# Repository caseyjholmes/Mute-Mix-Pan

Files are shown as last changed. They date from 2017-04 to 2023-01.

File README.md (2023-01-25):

# Mute-Mix-Pan

NOTE:
this is an outdated version of my mixer. use the new MMPV3 repository files

5 Channel Mono Mutable Mixer with Pan output for Eurorack

A simple knob controlled 5 channel mono eurorack mixer with mute switches, master volume and panning balance outputs. 
Component values are printed on the board. Minimum component size is 0805.

Install switches first, then front panel. The switches are "tall". Solder in jacks to the right height after the switches are in place. Finally, you can solder in the potentiometers. 

Panel has been added now.

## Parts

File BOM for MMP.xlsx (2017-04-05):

VR1-5 | Vertical B1M Linear 9mm rotary potentiometer | Thonk https://www.thonk.co.uk/shop/alpha-9mm-pots/
VR6, VR7 | Vertical B10K Linear 9mm rotary potentiometer | Thonk https://www.thonk.co.uk/shop/alpha-9mm-pots/
R1-R5,R17-R21, R25, R26 | 1K 0805 SMD resistor 603-RC0805FR-071K5L | Mouser
R6-R16, R22, R23, R24 | 100K 0805 SMD resistor 603-RC0805FR-07100KL | Mouser
C1-5 | 10uf 35v Aluminum Electrolytic Cap 667-EEE-FK1V100UR | Mouser
C6,C7 | 47uf 35v Aluminum Electrolytic Cap 667-EEE-FK1V470P | Mouser
C8-C11 | 100n 25v 0805 SMD Cap 81-GRM40X104K25L | Mouser
D1,D2 | 1N5817 Through Hole diodes 621-1N5817 | Mouser
LED1-5 | 3mm Through Hold Light Emitting Diodes 604-WP710A10GT | Mouser
LED6 | 5mm Through Hole Light Emitting Diode 604-WP1503GD | Mouser
IC1,IC2 | TL074 Quad Op Amp SMD SOIC14 package 595-TL074CDR | Mouser
POWER (header) | 2 row 5 pin .1" spacing Power Header 649-67996-410HLF | Mouser
J1-9 | Thonkicon 3.5mm Jack PJ301M-12 | Thonk, Modular Addict
SW1-5 | On/On SPDT Miniture (not micro) Toggle Switches | Thonk https://www.thonk.co.uk/shop/turing-mk-ii-write-switch/
knobs | 7 knobs to fit potentiometers | Ebay, AliExpress, Mouser, Modular Addict, Thonk

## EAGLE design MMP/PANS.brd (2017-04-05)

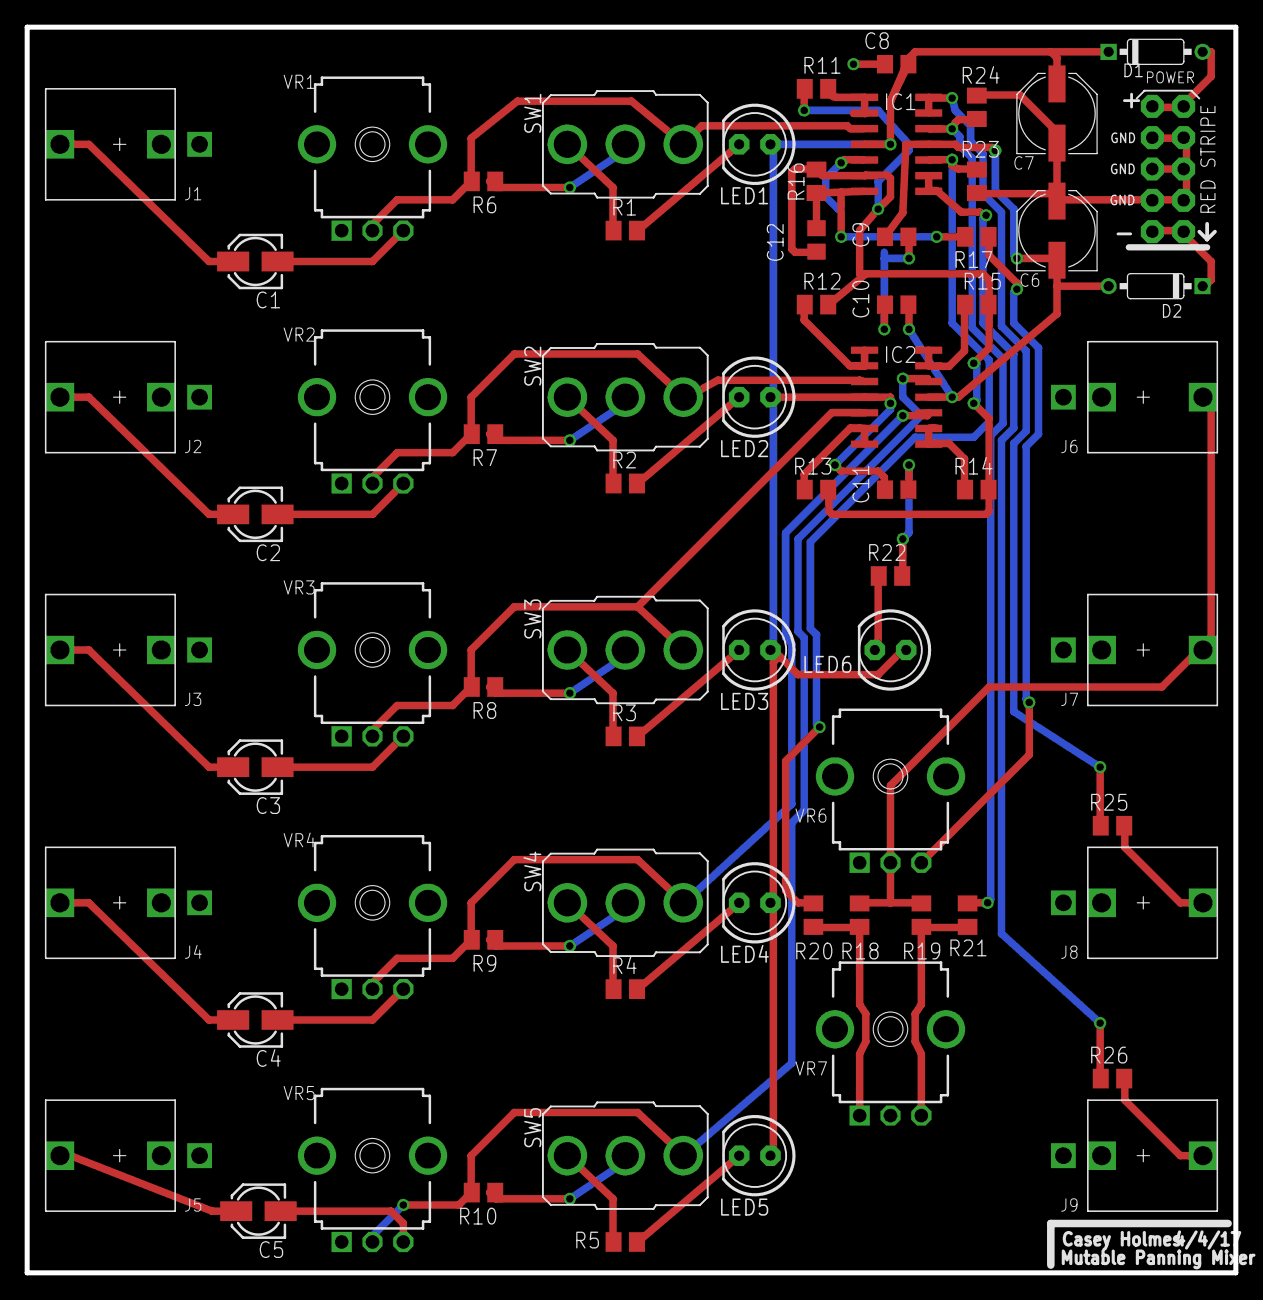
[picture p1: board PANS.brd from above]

Board: 2 copper layers, 98.0 x 101.0 mm, 70 parts (0 on the bottom side), 48 nets.

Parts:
C1, C2, C3, C4, C5: 10uf; 153CLV-0405
C6, C7: 47uf; PANASONIC_D
C8, C9, C10, C11: 100n; C0805
C12: XXX; C0805
D1, D2: 1N5817; DO35-7
IC1, IC2: TL074; SO14
J1, J2, J3, J4, J5, J6, J7, J8, J9: THONKICONNOLD; THONKICONN
LED1, LED2, LED3, LED4, LED5, LED6: green; LED5MM
R1, R2, R3, R4, R5, R17, R18, R19, R20, R21, R25, R26: 1K; M0805
R6, R7, R8, R9, R10, R11, R12, R13, R14, R15, R16, R22, R23, R24: 100K; M0805
SV1: SV1; EURO_PWR_HEADER_FAT
SW1, SW2, SW3, SW4, SW5: on/on; M9040P
VR1, VR2, VR3, VR4, VR5: 1M; 9MM_SNAP-IN_POT
VR6, VR7: 10K; 9MM_SNAP-IN_POT

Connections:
GND: C6.+, C7.-, C8.1, C9.1, C10.1, C11.2, IC1.5, J1.P$1_SLEEVE, J2.P$1_SLEEVE, J3.P$1_SLEEVE, J4.P$1_SLEEVE, J5.P$1_SLEEVE, J6.P$1_SLEEVE, J7.P$1_SLEEVE, J8.P$1_SLEEVE, J9.P$1_SLEEVE, R6.1, R7.1, R8.1, R9.1, R10.1, R22.2, R23.1, R24.2, SV1.3, SV1.4, SV1.5, SV1.6, SV1.7, SV1.8, SW1.2, SW2.2, SW3.2, SW4.2, SW5.2, VR1.1, VR2.1, VR3.1, VR4.1, VR5.1, VR6.1, VR7.2
S$1: C1.+, J1.P$3_TIP
S$2: C2.+, J2.P$3_TIP
S$3: C3.+, J3.P$3_TIP
S$4: C4.+, J4.P$3_TIP
S$5: C5.+, J5.P$3_TIP
S$6: C1.-, VR1.3
S$7: C2.-, VR2.3
S$8: C3.-, VR3.3
S$9: C4.-, VR4.3
S$10: C5.-, VR5.3
S$11: IC1.3, R6.2, SW1.3, VR1.2
S$12: IC2.3, R7.2, SW2.3, VR2.2
S$13: IC2.5, R8.2, SW3.3, VR3.2
S$14: IC2.10, R9.2, SW4.3, VR4.2
S$15: IC2.12, R10.2, SW5.3, VR5.2
S$16: D1.A, SV1.9, SV1.10
S$17: D2.C, SV1.1, SV1.2
S$18: LED5.K, R5.2
S$19: J6.P$3_TIP, J7.P$3_TIP, R18.2, R19.2, VR6.2
S$20: R18.1, R20.1, VR7.1
S$21: R19.1, R21.1, VR7.3
S$22: IC1.10, R20.2, R23.2
S$23: IC2.13, IC2.14, R15.1
S$24: IC1.8, IC1.9, R26.2
S$25: LED6.K, R22.1
S$26: R1.1, SW1.1
S$27: R2.1, SW2.1
S$28: R3.1, SW3.1
S$29: R4.1, SW4.1
S$30: R5.1, SW5.1
S$31: LED4.K, R4.2
S$34: IC1.13, IC1.14, R25.2
S$35: J8.P$3_TIP, R25.1
S$36: IC1.12, R21.2, R24.1
S$37: LED3.K, R3.2
S$38: LED2.K, R2.2
S$39: LED1.K, R1.2
S$41: J9.P$3_TIP, R26.1
S$42: IC2.1, IC2.2, R12.1
S$43: IC2.6, IC2.7, R13.1
S$45: IC2.8, IC2.9, R14.1
S$46: IC1.1, IC1.2, R11.2
S$47: R17.2, VR6.3
S$48: C6.-, C9.2, C10.2, D2.A, IC1.11, IC2.11
S$50: C12.2, IC1.6, R11.1, R12.2, R13.2, R14.2, R15.2, R16.2
S$51: C12.1, IC1.7, R16.1, R17.1
V+: C7.+, C8.2, C11.1, D1.C, IC1.4, IC2.4, LED1.A, LED2.A, LED3.A, LED4.A, LED5.A, LED6.A

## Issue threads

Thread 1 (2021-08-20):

Board / Schematic inconsitency

hanebuechenes, 2021-08-20:
The Files are inconsistent. Can you upload them again with the right versions?

caseyjholmes, 2023-01-24:
I have a new version coming out with better redesign within the next few days. Apologies for that. Not sure why that happened. I'll try and fix it soon. Check back for the new version shortly. I'm waiting for the panels to make sure they work before release.
Thanks for your inerest.
